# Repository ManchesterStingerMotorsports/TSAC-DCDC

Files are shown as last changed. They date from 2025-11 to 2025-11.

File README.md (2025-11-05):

# TSAC-DCDC
Low power HV-LV flyback converter to power the TSAC's internal safety circuitry.

Input voltage:

	Min: 35V to allow for single segment operation
	Max: 600V to allow for use across accumulator types

Estimated Output @ 12V with minimal ripple:

	6W continuous
	24W Peak

Webench design tool link for simulation and specs:
https://webench.ti.com/appinfo/webench/scripts/SDP.cgi?ID=1A791EA787B34855

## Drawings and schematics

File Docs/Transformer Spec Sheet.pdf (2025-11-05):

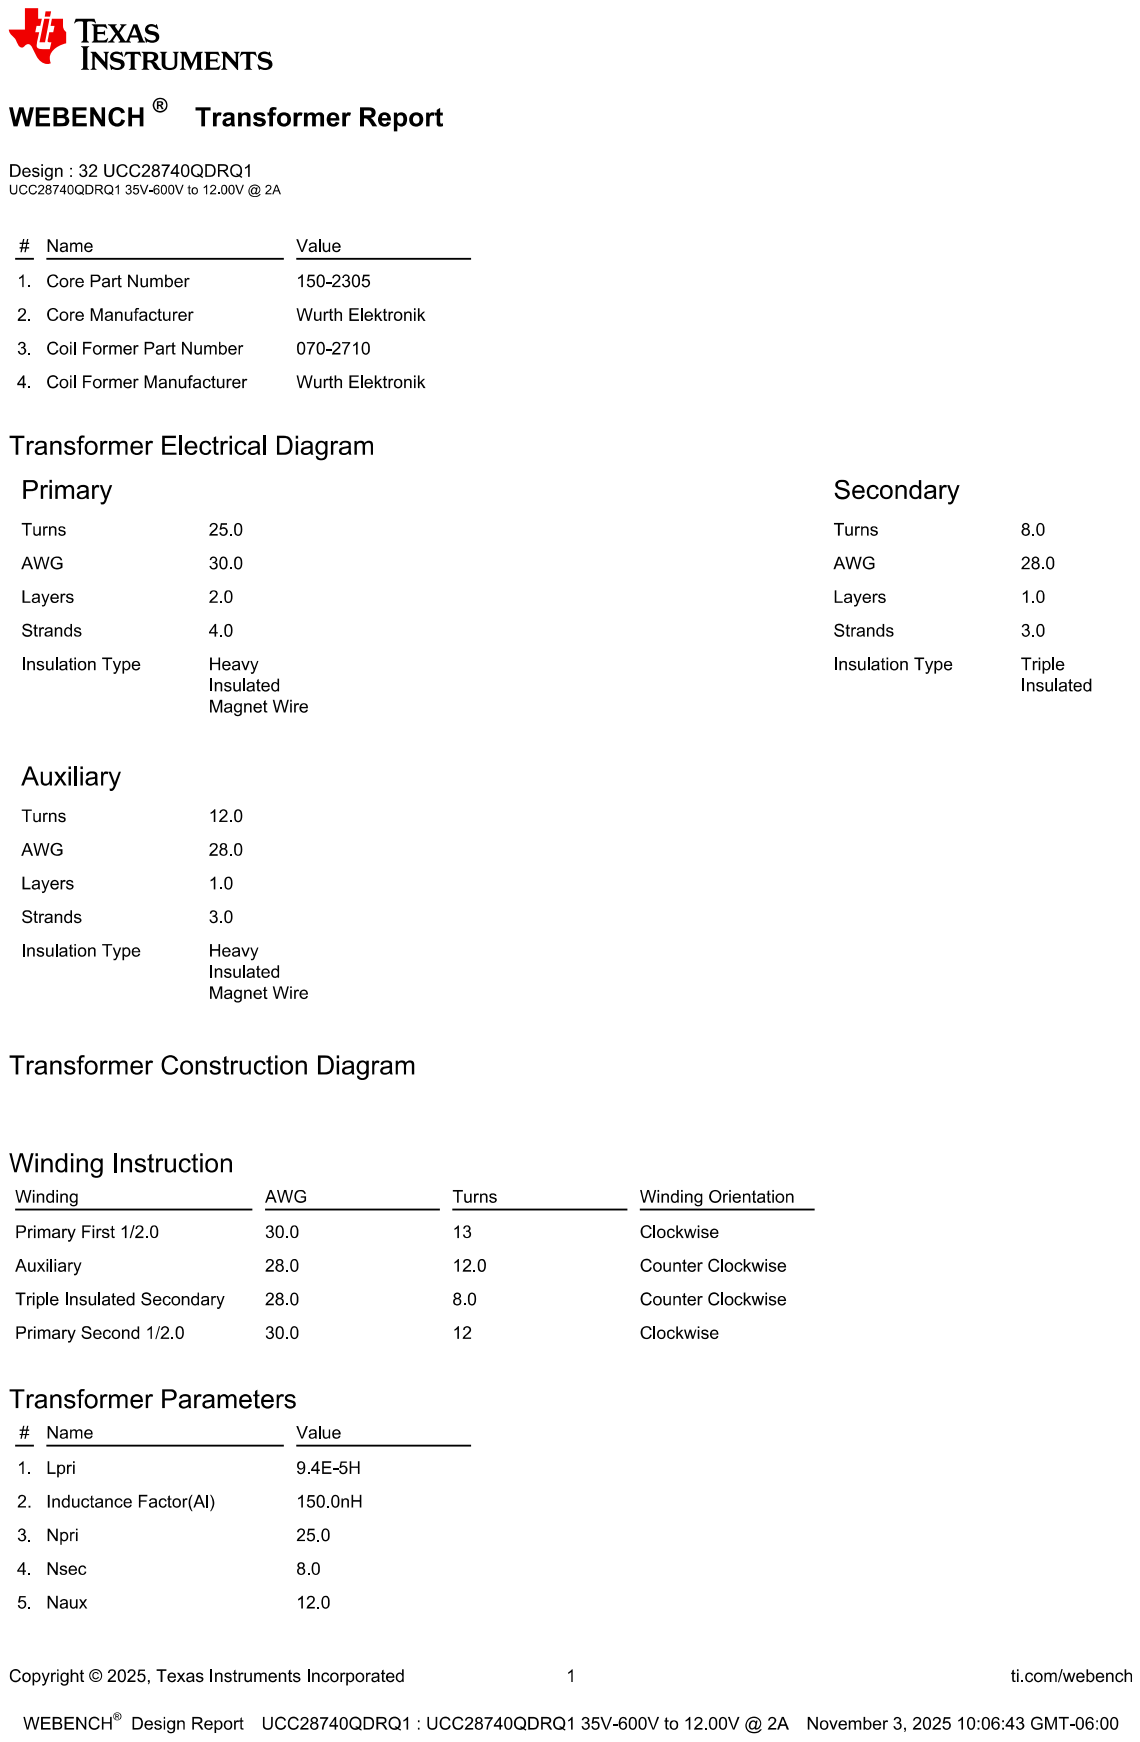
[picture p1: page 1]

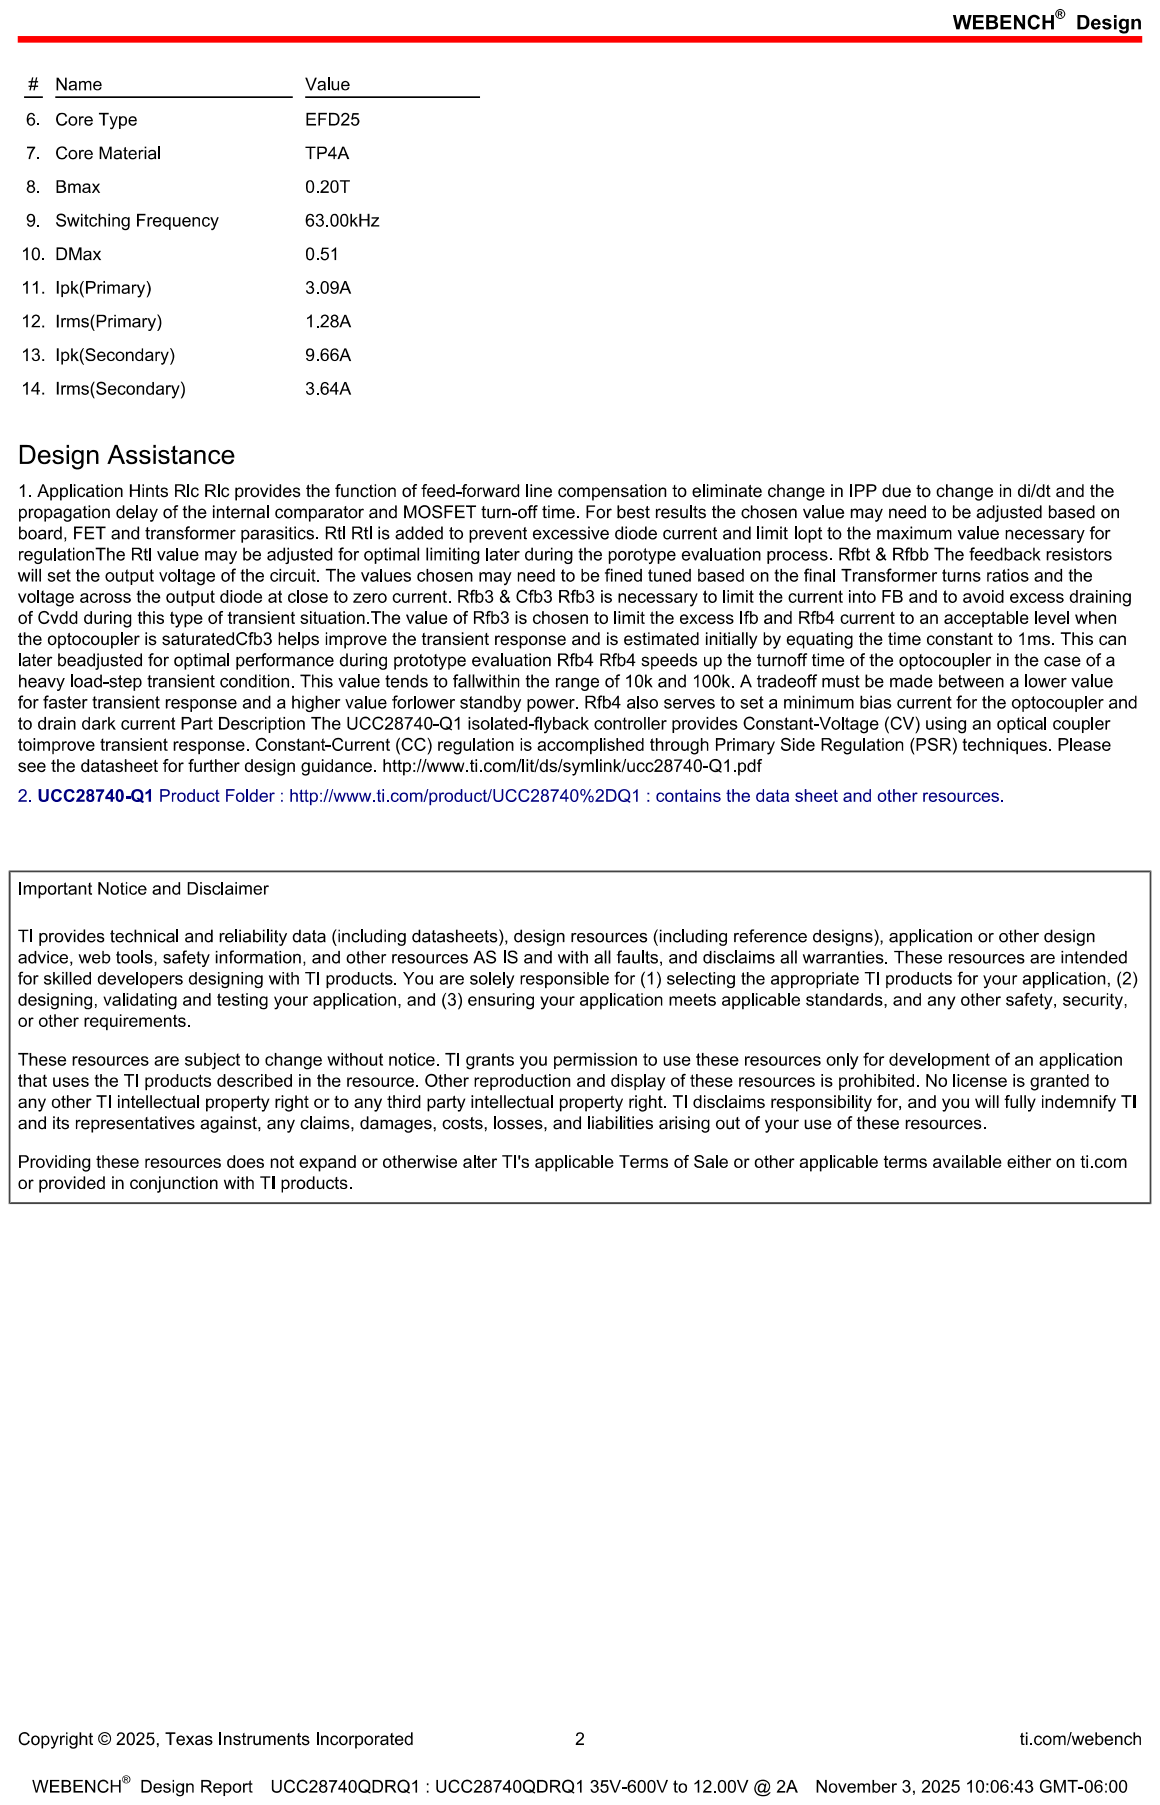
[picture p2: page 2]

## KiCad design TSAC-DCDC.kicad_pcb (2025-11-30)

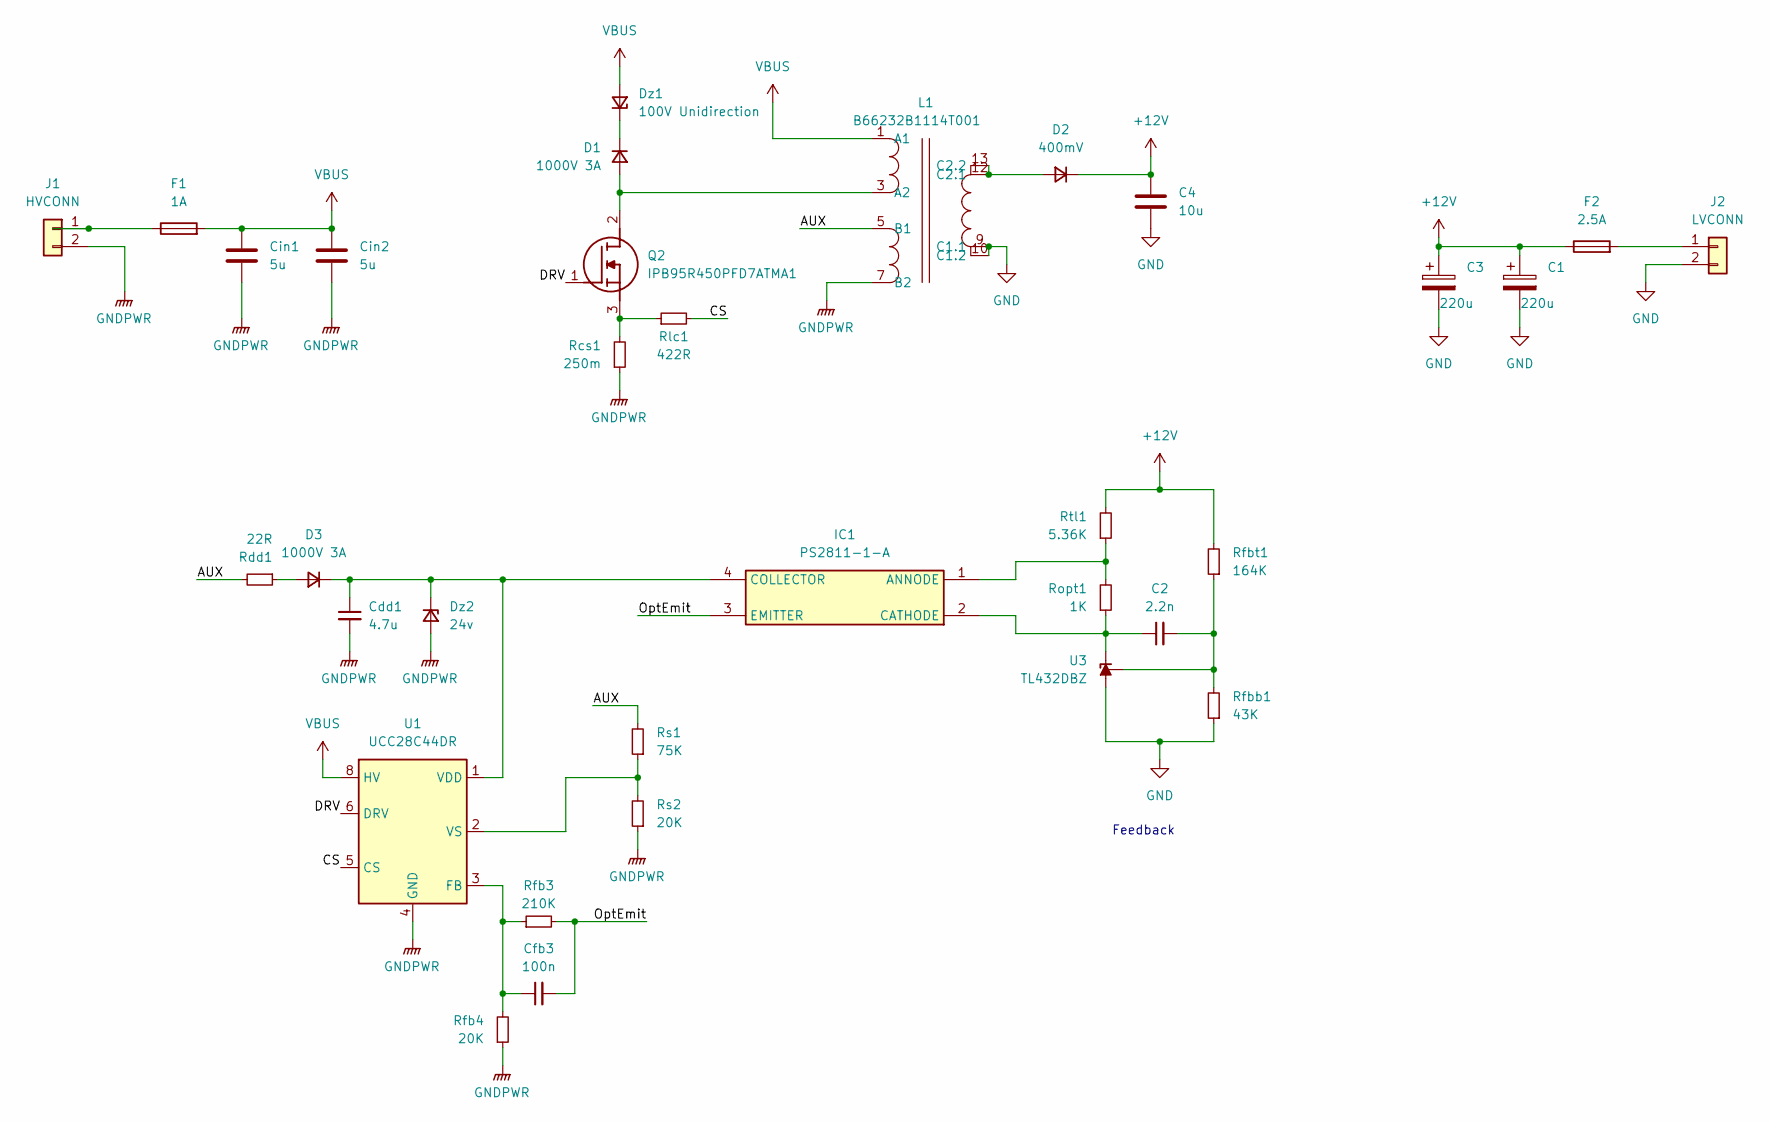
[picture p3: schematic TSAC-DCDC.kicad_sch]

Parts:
C1, C3: 220u; CP_Radial_D8.0mm_P3.50mm
C2: 2.2n; C_0603_1608Metric
C4: 10u; C_0603_1608Metric
Cdd1: 4.7u; C_0603_1608Metric
Cfb3: 100n; C_0603_1608Metric
Cin1, Cin2: 5u; ECWFG60505JA
D1, D3: 1000V 3A; D_SMB
D2: 400mV; TO-277A
Dz1: 100V Unidirection; D_SMC
Dz2: 24v; SOD-123-2
F1: 1A; FUSC13250X555N
F2: 2.5A; FUSC13250X555N
IC1: PS2811-1-A; SOIC127P700X210-4N; Mouser Part Number 551-PS2811-1-A
J1: HVCONN
J2: LVCONN
L1: B66232B1114T001; Mouser Part Number 871-B66232B1114T001
Q2: IPB95R450PFD7ATMA1; Mouser Part Number 726-IPB95R450PFD7ATM
Rcs1: 250m; R_0603_1608Metric
Rdd1: 22R; R_0603_1608Metric
Rfb3: 210K; R_0603_1608Metric
Rfb4: 20K; R_0603_1608Metric
Rfbb1: 43K; R_0603_1608Metric
Rfbt1: 164K; R_0603_1608Metric
Rlc1: 422R; R_0603_1608Metric
Ropt1: 1K; R_0603_1608Metric
Rs1: 75K; R_0603_1608Metric
Rs2: 20K; R_0603_1608Metric
Rtl1: 5.36K; R_0603_1608Metric
U1: UCC28C44DR; SOIC-8_3.9x4.9mm_P1.27mm
U3: TL432DBZ; SOT-23

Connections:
+12V: C1.1, C3.1, C4.1, D2.1 (K), F2.1, Rfbt1.2, Rtl1.2
/AUX: L1.5 (B1), Rdd1.2, Rs1.2
/CS: Rlc1.2, U1.5 (CS)
/DRV: Q2.1 (G), U1.6 (DRV)
/OptEmit: Cfb3.2, IC1.3 (EMITTER), Rfb3.2
GND: C1.2, C3.2, C4.2, J2.2, L1.9 (C1.1), L1.10 (C1.2), Rfbb1.1, U3.3 (A)
GNDPWR: Cdd1.2, Cin1.2, Cin2.2, Dz2.2 (A), J1.2, L1.7 (B2), Rcs1.1, Rfb4.1, Rs2.1, U1.4 (GND)
unnamed: D1.2 (A), L1.3 (A2), Q2.2 (D)
unnamed: D1.1 (K), Dz1.1 (K)
unnamed: D2.2 (A), L1.12 (C2.1), L1.13 (C2.2)
unnamed: D3.2 (A), Rdd1.1
unnamed: Cdd1.1, D3.1 (K), Dz2.1 (K), IC1.4 (COLLECTOR), U1.1 (VDD)
unnamed: IC1.1 (ANNODE), Ropt1.2, Rtl1.1
unnamed: C2.1, IC1.2 (CATHODE), Ropt1.1, U3.2 (K)
unnamed: F1.1, J1.1
unnamed: F2.2, J2.1
unnamed: Q2.3 (S), Rcs1.2, Rlc1.1
unnamed: Cfb3.1, Rfb3.1, Rfb4.2, U1.3 (FB)
unnamed: Rs1.1, Rs2.2, U1.2 (VS)
unnamed: C2.2, Rfbb1.2, Rfbt1.1, U3.1 (REF)
VBUS: Cin1.1, Cin2.1, Dz1.2 (A), F1.2, L1.1 (A1), U1.8 (HV)

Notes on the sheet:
Feedback

Board: 2 copper layers, 30 parts (0 on the bottom side), 19 nets, no tracks yet.

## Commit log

2025-11-06 Rearrange sch for cleaner look.
    [TSAC-DCDC.kicad_sch]
2025-11-06 transformer pin update
    [TSAC-DCDC.kicad_sch]
2025-11-11 Add fuse to power input and output
    [TSAC-DCDC.kicad_sch]
2025-11-12 Add footprint to components
    [TSAC-DCDC.kicad_pcb, TSAC-DCDC.kicad_sch]
2025-11-30 First try of L-C inperfection
    [TSAC-DCDC.kicad_pcb, TSAC-DCDC.kicad_sch]
2025-12-03 Initial PCB layout
    [TSAC-DCDC.kicad_pcb]
2025-12-08 Revert "Initial PCB layout"
    This reverts commit eb11546efb0268227655b0bea42a16ad7d7093c5.
    [TSAC-DCDC.kicad_pcb]
